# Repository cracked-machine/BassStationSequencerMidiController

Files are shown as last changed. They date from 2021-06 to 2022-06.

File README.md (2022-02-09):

## BassStationMidiController

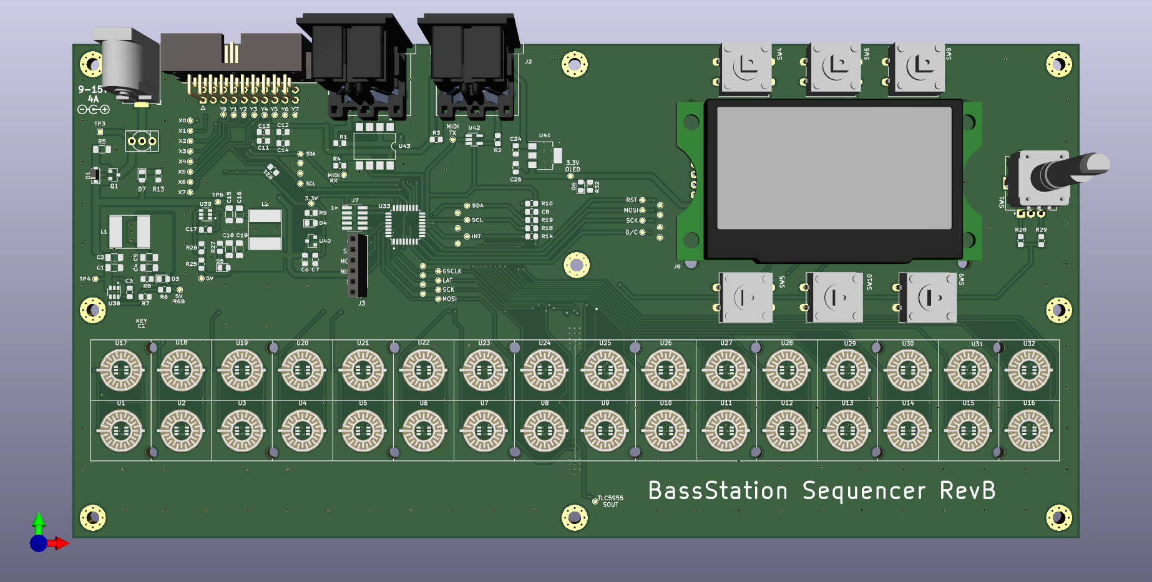
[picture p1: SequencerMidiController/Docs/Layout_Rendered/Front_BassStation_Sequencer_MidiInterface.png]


### Discussion and Design

- [Part1 – The Synth](https://www.bitshiftmyrobot.com/2021/05/26/novation-bass-station-sequencer-part1/)
- [Part2 – Output](https://www.bitshiftmyrobot.com/2021/06/08/novation-bass-station-sequencer-part2/)
- [Part3 - Input](https://www.bitshiftmyrobot.com/2021/06/08/novation-bass-station-sequencer-part3/)
- [Part4 - Power Supply](https://www.bitshiftmyrobot.com/2021/06/10/novation-bass-station-sequencer-part4/)
- [Part5 - User Interface](https://www.bitshiftmyrobot.com/2021/06/11/novation-bass-station-sequencer-part5-user-interface/)
- [Part6 - Final Design](https://www.bitshiftmyrobot.com/2021/06/13/novation-bass-station-sequencer-part6-bringing-it-all-together/)

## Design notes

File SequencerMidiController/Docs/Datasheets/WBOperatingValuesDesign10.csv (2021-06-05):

Name | Value | Category | Description
Vout | 5 V | System Information | Operational Output Voltage
Cin IRMS | 1.49 A | Capacitor | Input capacitor RMS ripple current
Cin Pd | 5.04 mW | Capacitor | Input capacitor power dissipation
Cout IRMS | 243.12 mA | Capacitor | Output capacitor RMS ripple current
Cout Pd | 109.64 µW | Capacitor | Output capacitor power dissipation
Duty Cycle | 57.59% | System Information | Duty cycle
Efficiency | 94.3% | System Information | Steady state efficiency
Frequency | 787.55 kHz | System Information | Switching frequency
IC Tj | 75.41 °C | IC | IC junction temperature
ICThetaJA | 62.9 °C/W | IC | IC junction-to-ambient thermal resistance
L Ipp | 842.18 mA | Inductor | Peak-to-peak inductor ripple current
L Pd | 181.18 mW | Inductor | Inductor power dissipation
IC Pd | 721.86 mW | IC | IC power dissipation
Pout | 15 W | System Information | Total output power
Iin Avg | 1.77 A | IC | Average input current
Mode | CCM | System Information | Conduction Mode
Vout p-p | 14.76 mV | System Information | Peak-to-peak output ripple voltage
IC Iq Pd | 1.51 mW | IC | IC Iq Pd
Total Pd | 908.53 mW | Power | Total Power Dissipation
FootPrint | 164 mm² | System Information | Total Foot Print Area of BOM components
Vin | 9 V | System Information | Vin operating point
Iout | 3 A | System Information | Iout operating point
Cin Pd | 5.04 mW | Power | Input capacitor power dissipation
Cout Pd | 109.64 µW | Power | Output capacitor power dissipation
L Pd | 181.18 mW | Power | Inductor power dissipation
IC Pd | 721.86 mW | Power | IC power dissipation
Vout Actual | 5.03 V | System Information | Vout Actual calculated based on selected voltage divider resistors
Vout Tolerance | 3.05% | System Information | Vout Tolerance based on IC Tolerance (no load) and voltage divider resistors if applicable
Total BOM | $1.00 | System Information | Total BOM Cost
BOM Count | 9 | System Information | Total Design BOM count

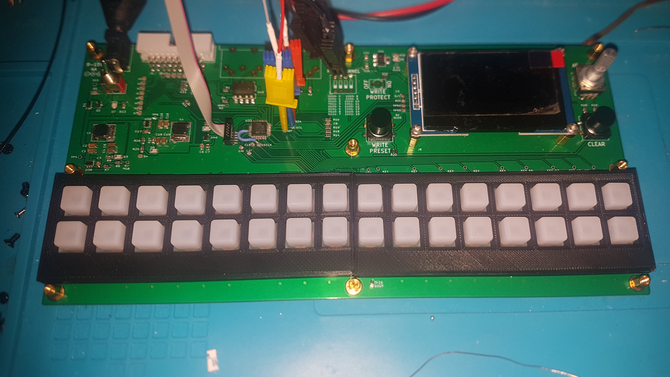
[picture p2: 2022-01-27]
keypad_spacers.jpg

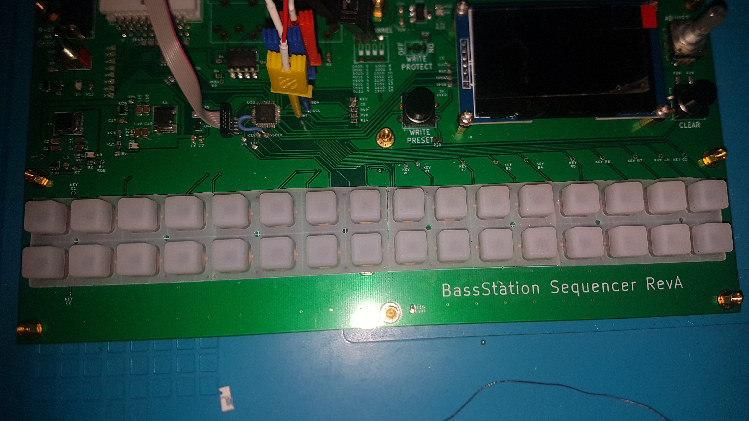
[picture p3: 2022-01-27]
without_keypad_spacer.jpg

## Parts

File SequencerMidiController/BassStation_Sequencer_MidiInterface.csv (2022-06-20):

Comment | Designator | Footprint | LCSC
100nF | C3,C8,C9,C10,C11,C12,C17,C20,C21 | Capacitor_SMD:C_0805_2012Metric_Pad1.18x1.45mm_HandSolder
10uF | C7,C13,C14 | Capacitor_SMD:C_0805_2012Metric_Pad1.18x1.45mm_HandSolder
10uF 20V X5R | C1,C2,C15,C16 | Resistor_SMD:R_1206_3216Metric_Pad1.30x1.75mm_HandSolder
22uF 10V X5R | C4,C5,C18,C19 | Resistor_SMD:R_1206_3216Metric_Pad1.30x1.75mm_HandSolder
4.7uF | C22,C23 | Capacitor_SMD:C_0805_2012Metric_Pad1.18x1.45mm_HandSolder
1uF | C6,C24,C25 | Capacitor_SMD:C_0805_2012Metric_Pad1.18x1.45mm_HandSolder
MMSZ4694T1G | D1 | Diode_SMD:D_SOD-123F
1N4148 | D2 | Diode_SMD:D_SOD-123F
RED | D3,D4,D5,D6,D7 | LED_SMD:LED_0805_2012Metric_Pad1.15x1.40mm_HandSolder
MIDI_IN | J1 | RS_5P180_DIN5_SOCKET_WSHIELD:RS_5P180_DIN5_SOCKET_WSHIELD
MIDI_OUT | J2 | RS_5P180_DIN5_SOCKET_WSHIELD:RS_5P180_DIN5_SOCKET_WSHIELD
Conn_01x06 | J3 | Connector_PinSocket_2.54mm:PinSocket_1x06_P2.54mm_Vertical
Conn_02x10_Odd_Even | J4 | Connector_IDC:IDC-Header_2x10_P2.54mm_Horizontal
Barrel_Jack_Switch | J5 | Connector_BarrelJack:BarrelJack_Horizontal
Conn_02x05_Odd_Even | J7 | Connector_PinHeader_1.27mm:PinHeader_2x05_P1.27mm_Vertical_SMD
Conn_01x07 | J8 | 2.42Inch_OLED_SSD1309:2.42Inch_OLED_SSD1309
Jumper_NC_Small | JP1,JP2,JP3 | Jumper:SolderJumper-2_P1.3mm_Bridged_RoundedPad1.0x1.5mm
4.7uH | L1,L2 | Inductor_SMD:L_Taiyo-Yuden_NR-80xx_HandSoldering
Si2323DS | Q1 | Package_TO_SOT_SMD:SOT-23
220R | R1,R2,R3 | Resistor_SMD:R_0805_2012Metric_Pad1.20x1.40mm_HandSolder
4K7 | R4,R10,R14,R18,R19 | Resistor_SMD:R_0805_2012Metric_Pad1.20x1.40mm_HandSolder
220R | R11,R12 | Capacitor_SMD:C_0805_2012Metric_Pad1.18x1.45mm_HandSolder
10K | R7,R21,R22,R23,R24,R26,R28,R29 | Resistor_SMD:R_0805_2012Metric_Pad1.20x1.40mm_HandSolder
56K | R6,R25 | Resistor_SMD:R_0805_2012Metric_Pad1.20x1.40mm_HandSolder
2K2 | R8,R9,R13,R27,R32 | Resistor_SMD:R_0805_2012Metric_Pad1.20x1.40mm_HandSolder
100R | R5 | Resistor_SMD:R_1206_3216Metric_Pad1.30x1.75mm_HandSolder
RotaryEncoder_Switch | SW1 | Rotary_Encoder:RotaryEncoder_Alps_EC12E-Switch_Vertical_H20mm
SW_SPST | SW3 | DailywellSwitches:Dailywell_SPDT
SW_SPST | SW4,SW5,SW6,SW8,SW9,SW10 | Button_Switch_THT:SW_PUSH-12mm
TestPoint | TP3 | TestPoint:TestPoint_Pad_1.0x1.0mm
TestPoint | TP1,TP2,TP4,TP5,TP6,TP7,TP8,TP9,TP10,TP11,TP12,TP13,TP14,TP15,TP16,TP17,TP18,TP19,TP20,TP21,TP22,TP23,TP32,TP33,TP34,TP35,TP36,TP37,TP38,TP39,TP40,TP41,TP42,TP43,TP44,TP45,TP46,TP47,TP48,TP49,TP50,TP51,TP52,TP53,TP54,TP55,TP56,TP57,TP58,TP59,TP60 | TestPoint:TestPoint_Pad_D1.0mm
PCB-SPST_RGB-LED-Counter-Clockwise | U1,U2,U3,U4,U5,U6,U7,U8,U9,U10,U11,U12,U13,U14,U15,U16,U17,U18,U19,U20,U21,U22,U23,U24,U25,U26,U27,U28,U29,U30,U31,U32 | PCB_SW_LED:Circular_3mm_10mm_Cree_PLLC6_CLY6D-FKC-CK1N1D1BB7D3D3
STM32G0B1_KxTxN_LQFP32 | U33 | Package_QFP:LQFP-32_7x7mm_P0.8mm
ADG2188 | U34 | Package_DFN_QFN:QFN-32-1EP_5x5mm_P0.5mm_EP3.1x3.1mm_ThermalVias
ADP5587-ACPZ_LFCSP24 | U35 | Package_CSP:LFCSP-24-1EP_4x4mm_P0.5mm_EP2.3x2.3mm
TLC5955DCA_HTSSOP56 | U36,U37 | Package_SO:HTSSOP-56-1EP_6.1x14mm_P0.5mm_EP3.61x6.35mm
TPS563200 | U38,U39 | Package_TO_SOT_SMD:SOT-23-6
SE8233X2 | U40 | Package_TO_SOT_SMD:SOT-23
MCP1703A-3302_SOT223 | U41 | Package_TO_SOT_SMD:SOT-223-3_TabPin2
74LVC1G34 | U42 | Package_TO_SOT_SMD:SOT-23-5_HandSoldering
6N135S | U43 | Package_DIP:SMDIP-8_W9.53mm

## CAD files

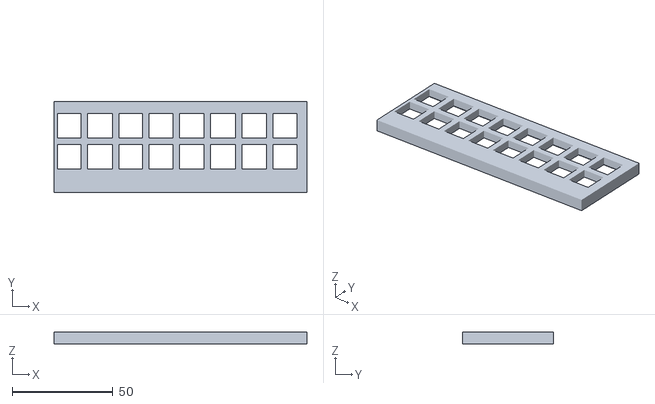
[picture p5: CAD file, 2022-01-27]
KeyPadSpacer_mirroredV0.8 v11.stl
125.4 x 45.0 x 6.00

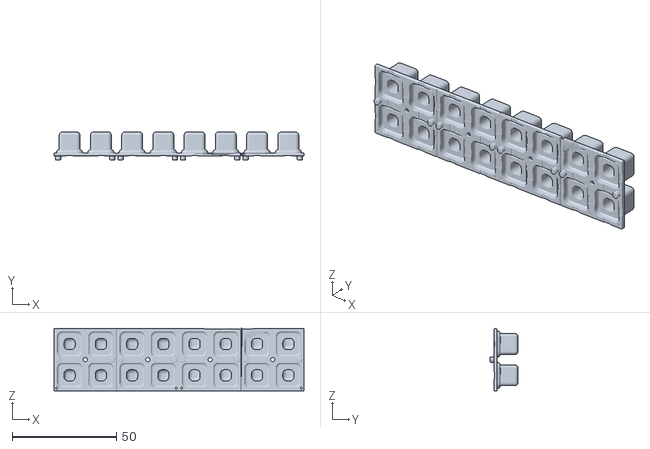
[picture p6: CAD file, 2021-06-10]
SequencerMidiController/Docs/3d/Adafruit1611_2x8_joined-Adafruit_Trellis_3mm_002.stl
120.0 x 13.5 x 30.2

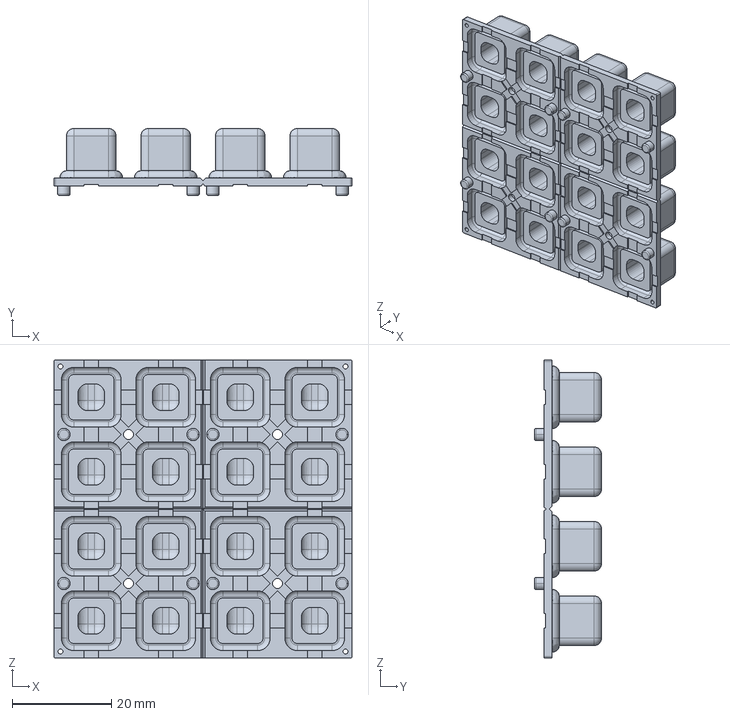
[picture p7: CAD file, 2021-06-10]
SequencerMidiController/Docs/3d/Adafruit Trellis 3mm.stp
60.0 x 13.5 x 60.0 mm

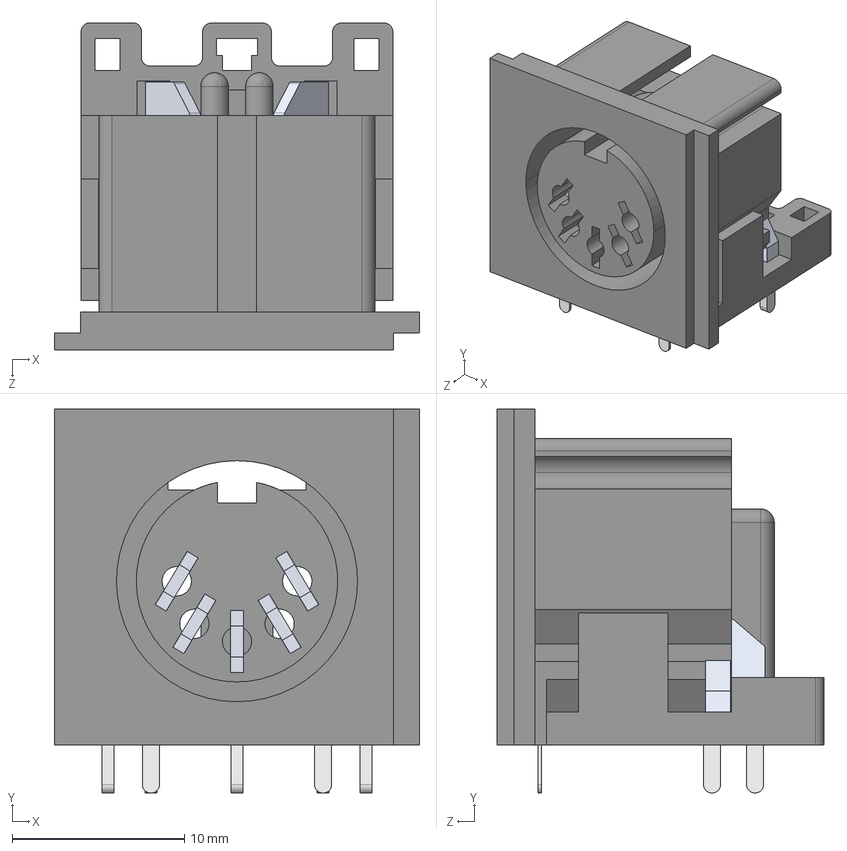
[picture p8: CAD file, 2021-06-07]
SequencerMidiController/Docs/3d/User Library-DIN-5.STEP
21.2 x 22.3 x 19.0 mm
DIN5 A
DIN5 B
DIN5 C
DIN D x 2
DIN E x 2
DIN EE x 2
DIN G
DIN DD x 2

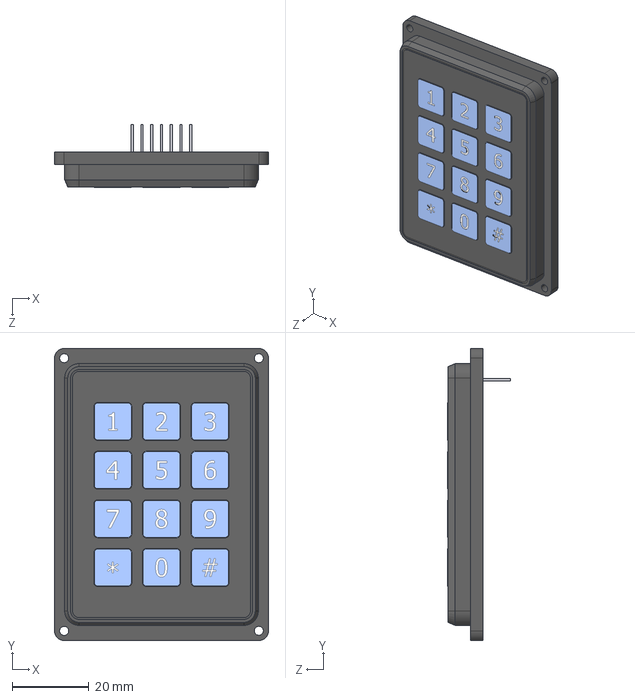
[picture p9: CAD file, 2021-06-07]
SequencerMidiController/Docs/3d/User Library-GrayhillKeypad.STEP
55.9 x 76.2 x 16.4 mm

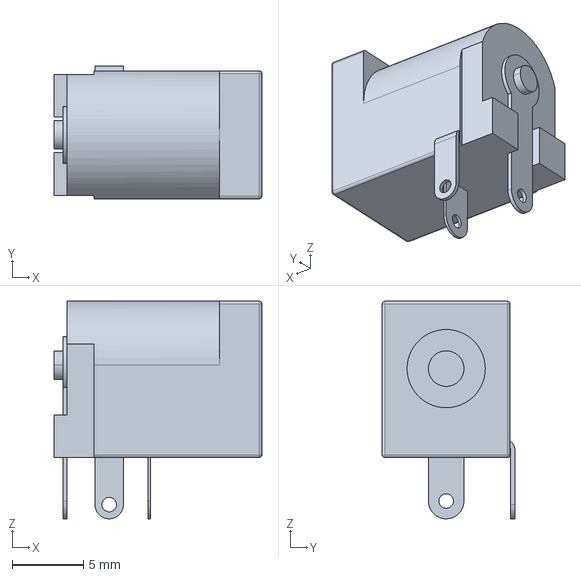
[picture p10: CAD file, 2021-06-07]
SequencerMidiController/Docs/3d/EJ503B-ND.stp
14.6 x 9.32 x 15.3 mm

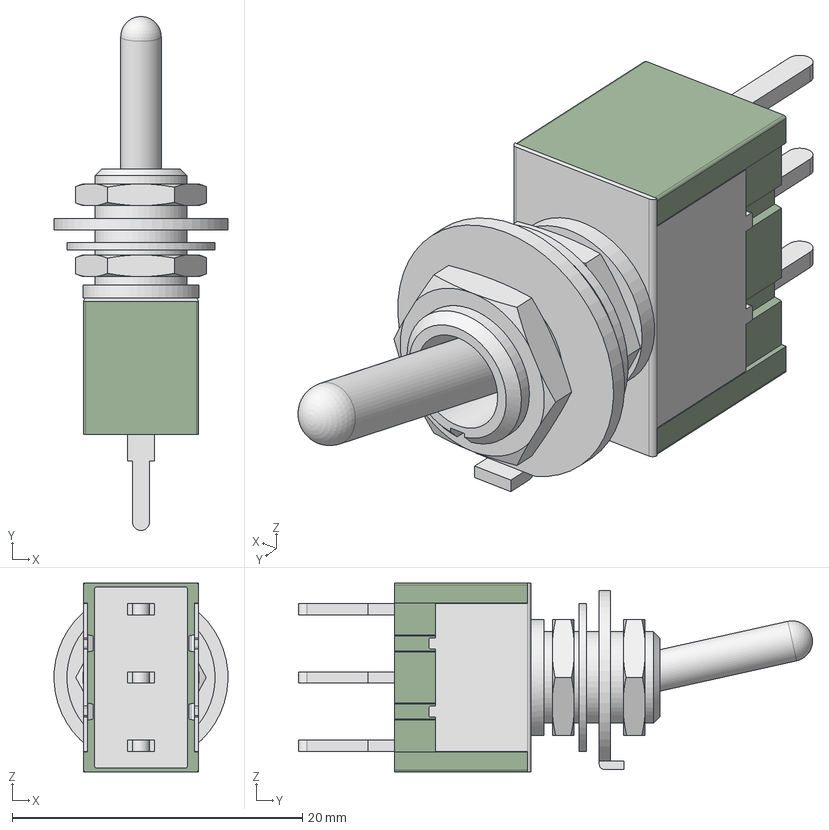
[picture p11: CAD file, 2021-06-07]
SequencerMidiController/Docs/3d/M2012SS1W03.stp
12.0 x 35.4 x 13.0 mm
_M20121SS1W03-switch
_M201S1M201-bushing
_AT513H x 2
_AT507H
_AT509
_M201203-terminals
_M20S-toggles
_M20S-caps

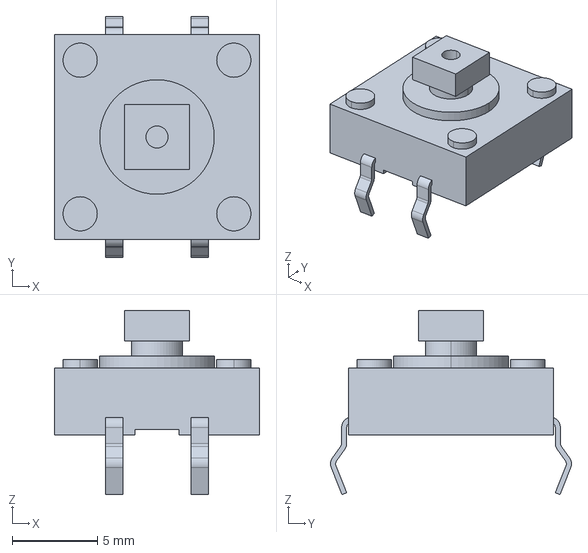
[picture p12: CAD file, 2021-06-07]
SequencerMidiController/Docs/3d/c-1571627-1-e-3d.stp
12.0 x 14.1 x 10.8 mm

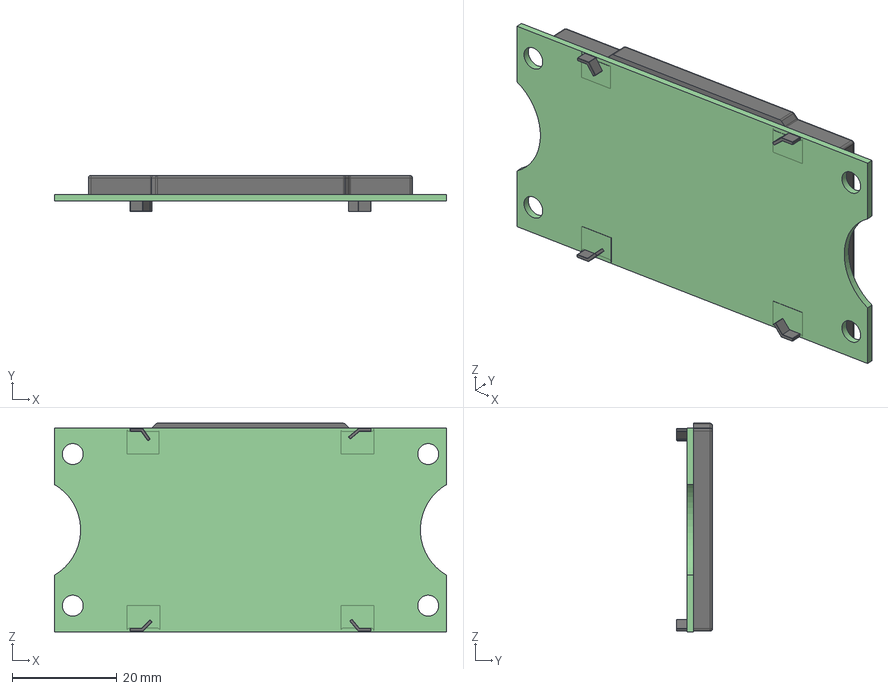
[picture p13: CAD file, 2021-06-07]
SequencerMidiController/Docs/3d/242-oled-v2.step
75.0 x 6.95 x 39.9 mm

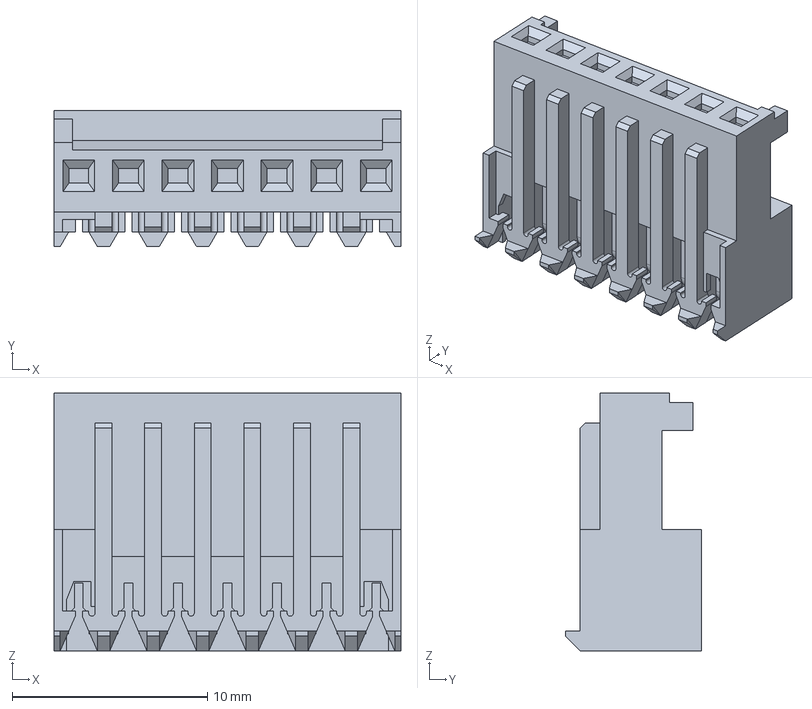
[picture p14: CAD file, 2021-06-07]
SequencerMidiController/Docs/3d/c-3-643813-7-k-3d.stp
17.8 x 6.98 x 13.2 mm

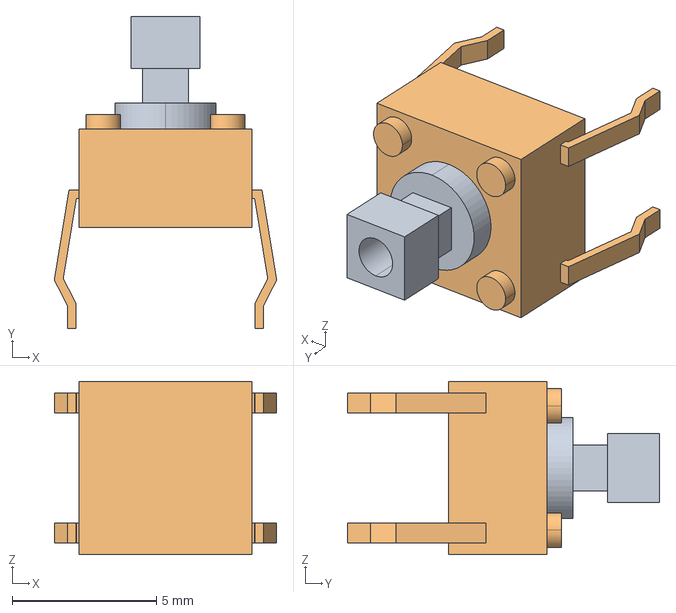
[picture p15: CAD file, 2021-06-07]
SequencerMidiController/Docs/3d/b3f-1056.stp
7.70 x 10.8 x 6.00 mm

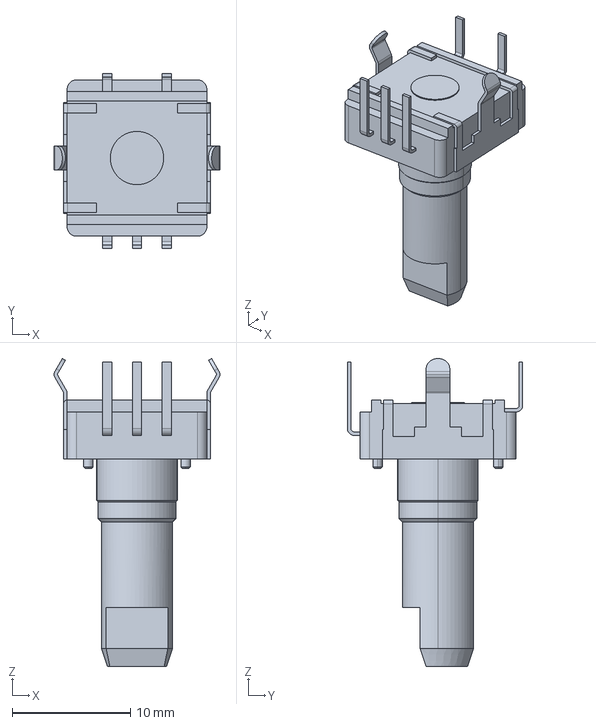
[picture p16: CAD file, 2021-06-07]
SequencerMidiController/Docs/3d/2-1879314-2.stp
14.0 x 14.8 x 26.0 mm

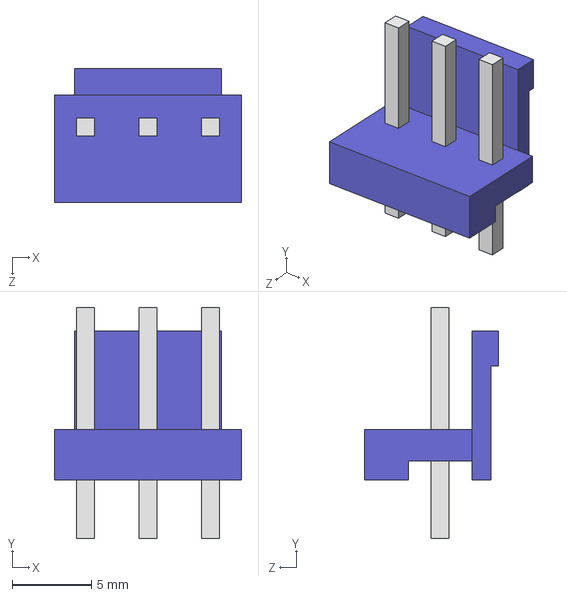
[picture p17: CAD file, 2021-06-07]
SequencerMidiController/Docs/3d/B3P-VH-B.STEP
11.8 x 14.6 x 8.50 mm

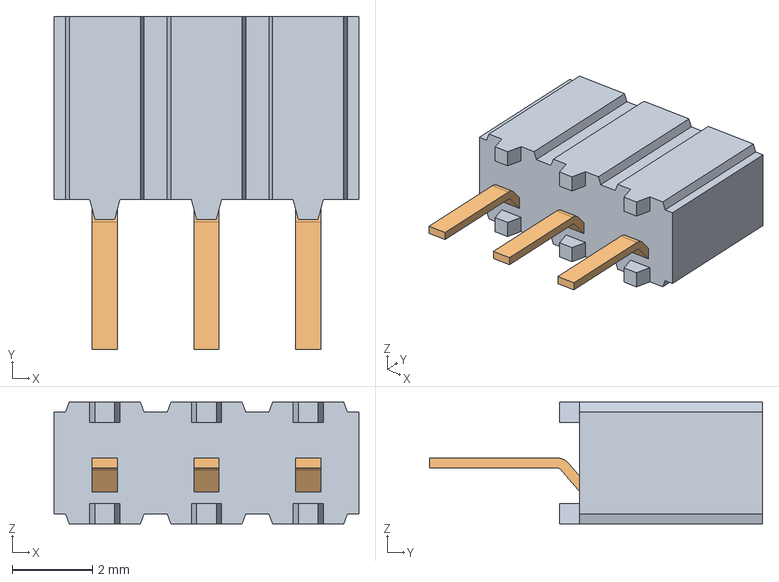
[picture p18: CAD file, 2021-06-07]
SequencerMidiController/Docs/3d/CES-103-01-L-S.stp
7.62 x 8.33 x 3.05 mm
_CES-103-01-S_socket
_C-45-01-03-S

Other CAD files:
KeyPadSpacerV0.8 v11.stl
SequencerMidiController/Docs/3d/89f2962_221790-1.stp
SequencerMidiController/Docs/3d/User Library-Eagle Plastic Devices 45KN018-GRX.STEP
SequencerMidiController/Docs/3d/s2751-46r.stp
SequencerMidiController/Docs/3d/010321021 2.stp
SequencerMidiController/Docs/3d/430450412.stp
SequencerMidiController/Docs/3d/475710001.stp
SequencerMidiController/Docs/3d/559320410.stp
SequencerMidiController/Docs/3d/559320430.stp
SequencerMidiController/Docs/3d/Adafruit Trellis 3mm.stl

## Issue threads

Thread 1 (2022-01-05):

Incorrect silkscreen labelling

cracked-machine, 2022-01-05:
Silk screen: SPI2_CLK and SPI2_LAT labels are incorrectly labelled. They should be switched.

cracked-machine, 2022-02-08:
f82aacb069ef6d8708b5c2ace1307a179e7129ae

Closed 2022-02-08.

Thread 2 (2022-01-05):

STM32G0B1 should use PB6 not PC14 for GSCLK

cracked-machine, 2022-01-05:
PC14 (Pin2) GPIO is too slow (OSC32_IN) for GSCLK.
PB6 (Pin30) GPIO is available and can run much faster.

cracked-machine, 2022-02-08:
f82aacb069ef6d8708b5c2ace1307a179e7129ae

Closed 2022-02-08.

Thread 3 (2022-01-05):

OLED test points are missing their (meaningful) SPI labels

cracked-machine, 2022-01-05:
`TP54` should be `MOSI`
`TP55` should be `SCK`

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

Closed 2022-02-08.

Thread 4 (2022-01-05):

TLC5955 LED driver (U37) should connect SOUT to MCU GPIO for diagnostics

cracked-machine, 2022-01-05:
The datasheet makes this recommendation for `SOUT`

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

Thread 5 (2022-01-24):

"reset" button should be connected to GPIO

cracked-machine, 2022-01-24:
This button would be more useful as a functional button. Maybe replace write protect switch connection to ADP5587, if this switch is no longer needed.

cracked-machine, 2022-02-09:
Reset button removed and more user buttons have been included.

Closed 2022-02-09.

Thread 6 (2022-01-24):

Can SDCard connecter share SPI2 with TLC5955?

cracked-machine, 2022-01-24:
This would allow backup of patterns. Might have issues sharing SPI2 with tlc5955. Obviously sequencer LEDs wwould have to be disabled/frozen while read/write was being done during pattern load/save, but this would be done infrequently upon user request only, so it won't interfere with TLC5955 during normal operation.

cracked-machine, 2022-02-09:
Need to test this with RevA board before committing to a new design.

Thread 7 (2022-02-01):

Add more momentary input buttons below display

cracked-machine, 2022-02-01:

cracked-machine, 2022-02-09:
584c196522adec800601e53ccd521e4a89dbfc55

Closed 2022-02-09.

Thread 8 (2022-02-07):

Add output for volt per division CV

cracked-machine, 2022-02-07:

cracked-machine, 2022-02-09:
Use DAC1_OUT1 on PA4.

cracked-machine, 2022-02-09:
Would need to move 3.3v LDO `MCP1703A-3302_SOT223` (U41)

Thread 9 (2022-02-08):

Add ground test points for every signal test point

cracked-machine, 2022-02-08:

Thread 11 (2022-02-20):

Add ability to detect keypresses from bass station keyboard

cracked-machine, 2022-02-20:
1. User starts the sequencer, the pattern is run
2. User presses a key on the bass station keyboard
3. The sequencer enables the current pattern step and sets it to that note.

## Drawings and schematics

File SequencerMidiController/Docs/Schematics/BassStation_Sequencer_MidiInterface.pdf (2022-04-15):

Input Keyscan and RGB LED Driver

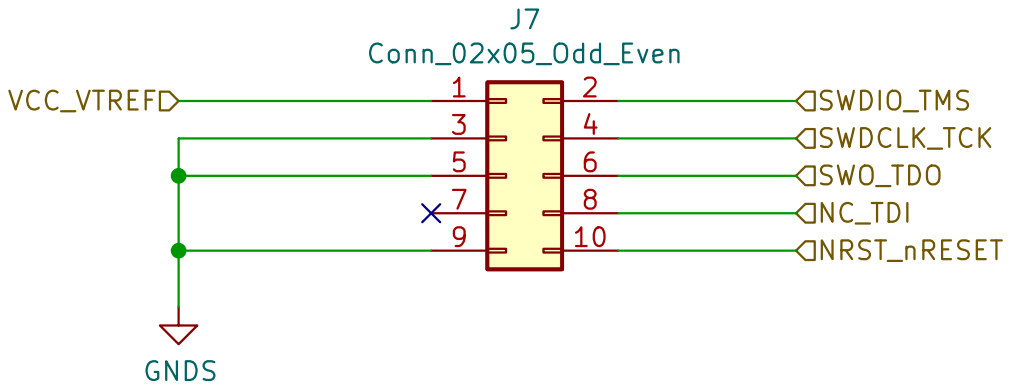
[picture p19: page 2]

File: 10PinARMSWD.kicad_sch Sheet: /MCU/10PinARMSWD/ Created by C Sutton GNDS

Id: 2/47 Title: Debug Connector

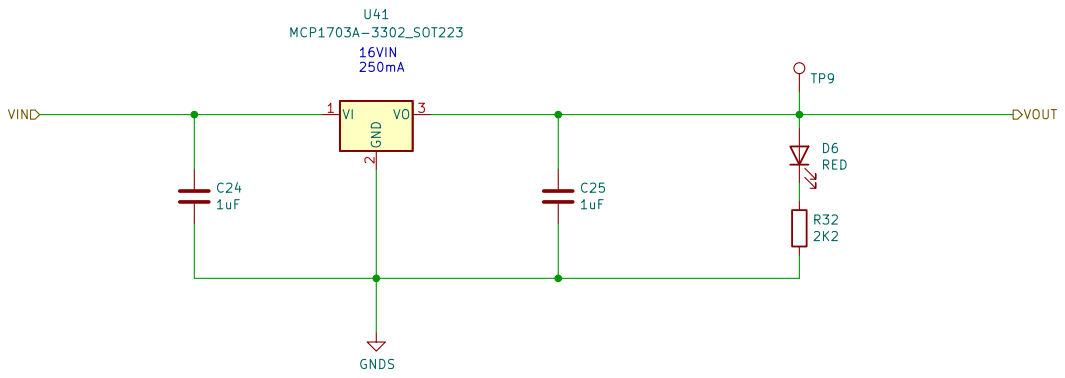
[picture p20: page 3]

Created by C Sutton
Sheet: /PSU/2_42Inch_OLED_LDO/
File: 2_42Inch_OLED_LDO.kicad_sch
Id: 3/47 Title: PSU - LDO 3.3V @ 250mA

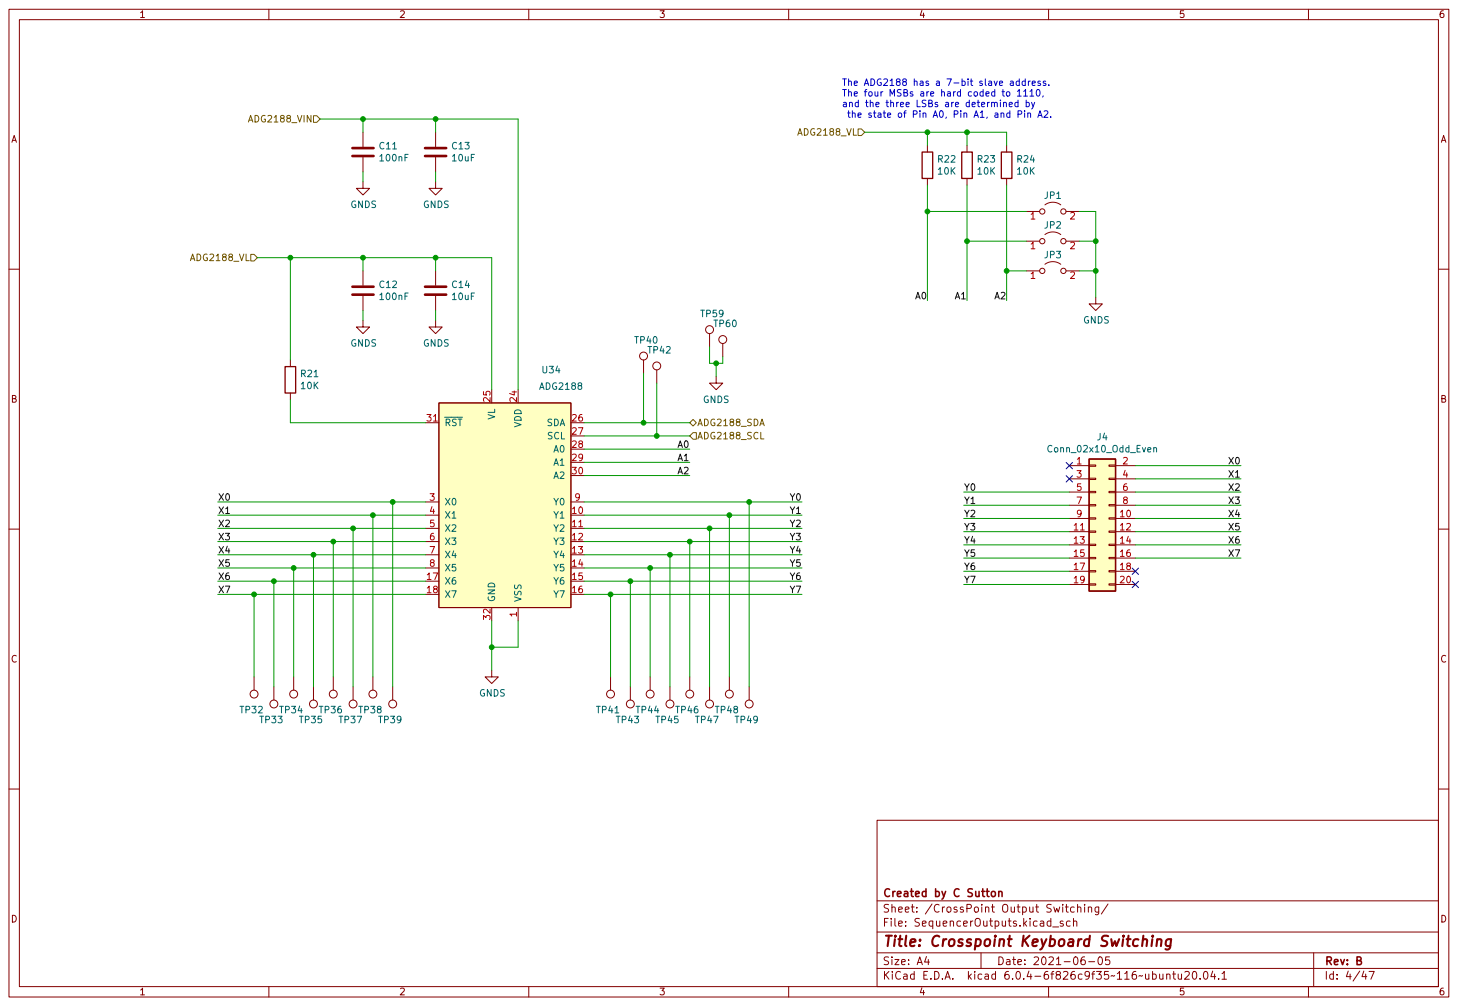
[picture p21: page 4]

The ADG2188 has a 7-bit slave address. The four MSBs are hard coded to 1110, and the three LSBs are determined by

the state of Pin A0, Pin A1, and Pin A2.

1 Y1 10 Y2 11 Y3 12 Y4 13 Y5 14 Y6 15 Y7 16 X6 17 X7 18 VDD 24 VL 25 SDA 26 SCL 27 A0 28 A1 29 X0 3 A2 30 ~{RST} 31 GND 32 X1 4 X2 5 X3 6 X4 7 X5 8 Y0 9 U34 ADG2188 R24

Created by C Sutton
Sheet: /CrossPoint Output Switching/
File: SequencerOutputs.kicad_sch
Id: 4/47 Title: Crosspoint Keyboard Switching

File: Encoder.kicad_sch Sheet: /MCU/Encoder/ Created by C Sutton GNDS

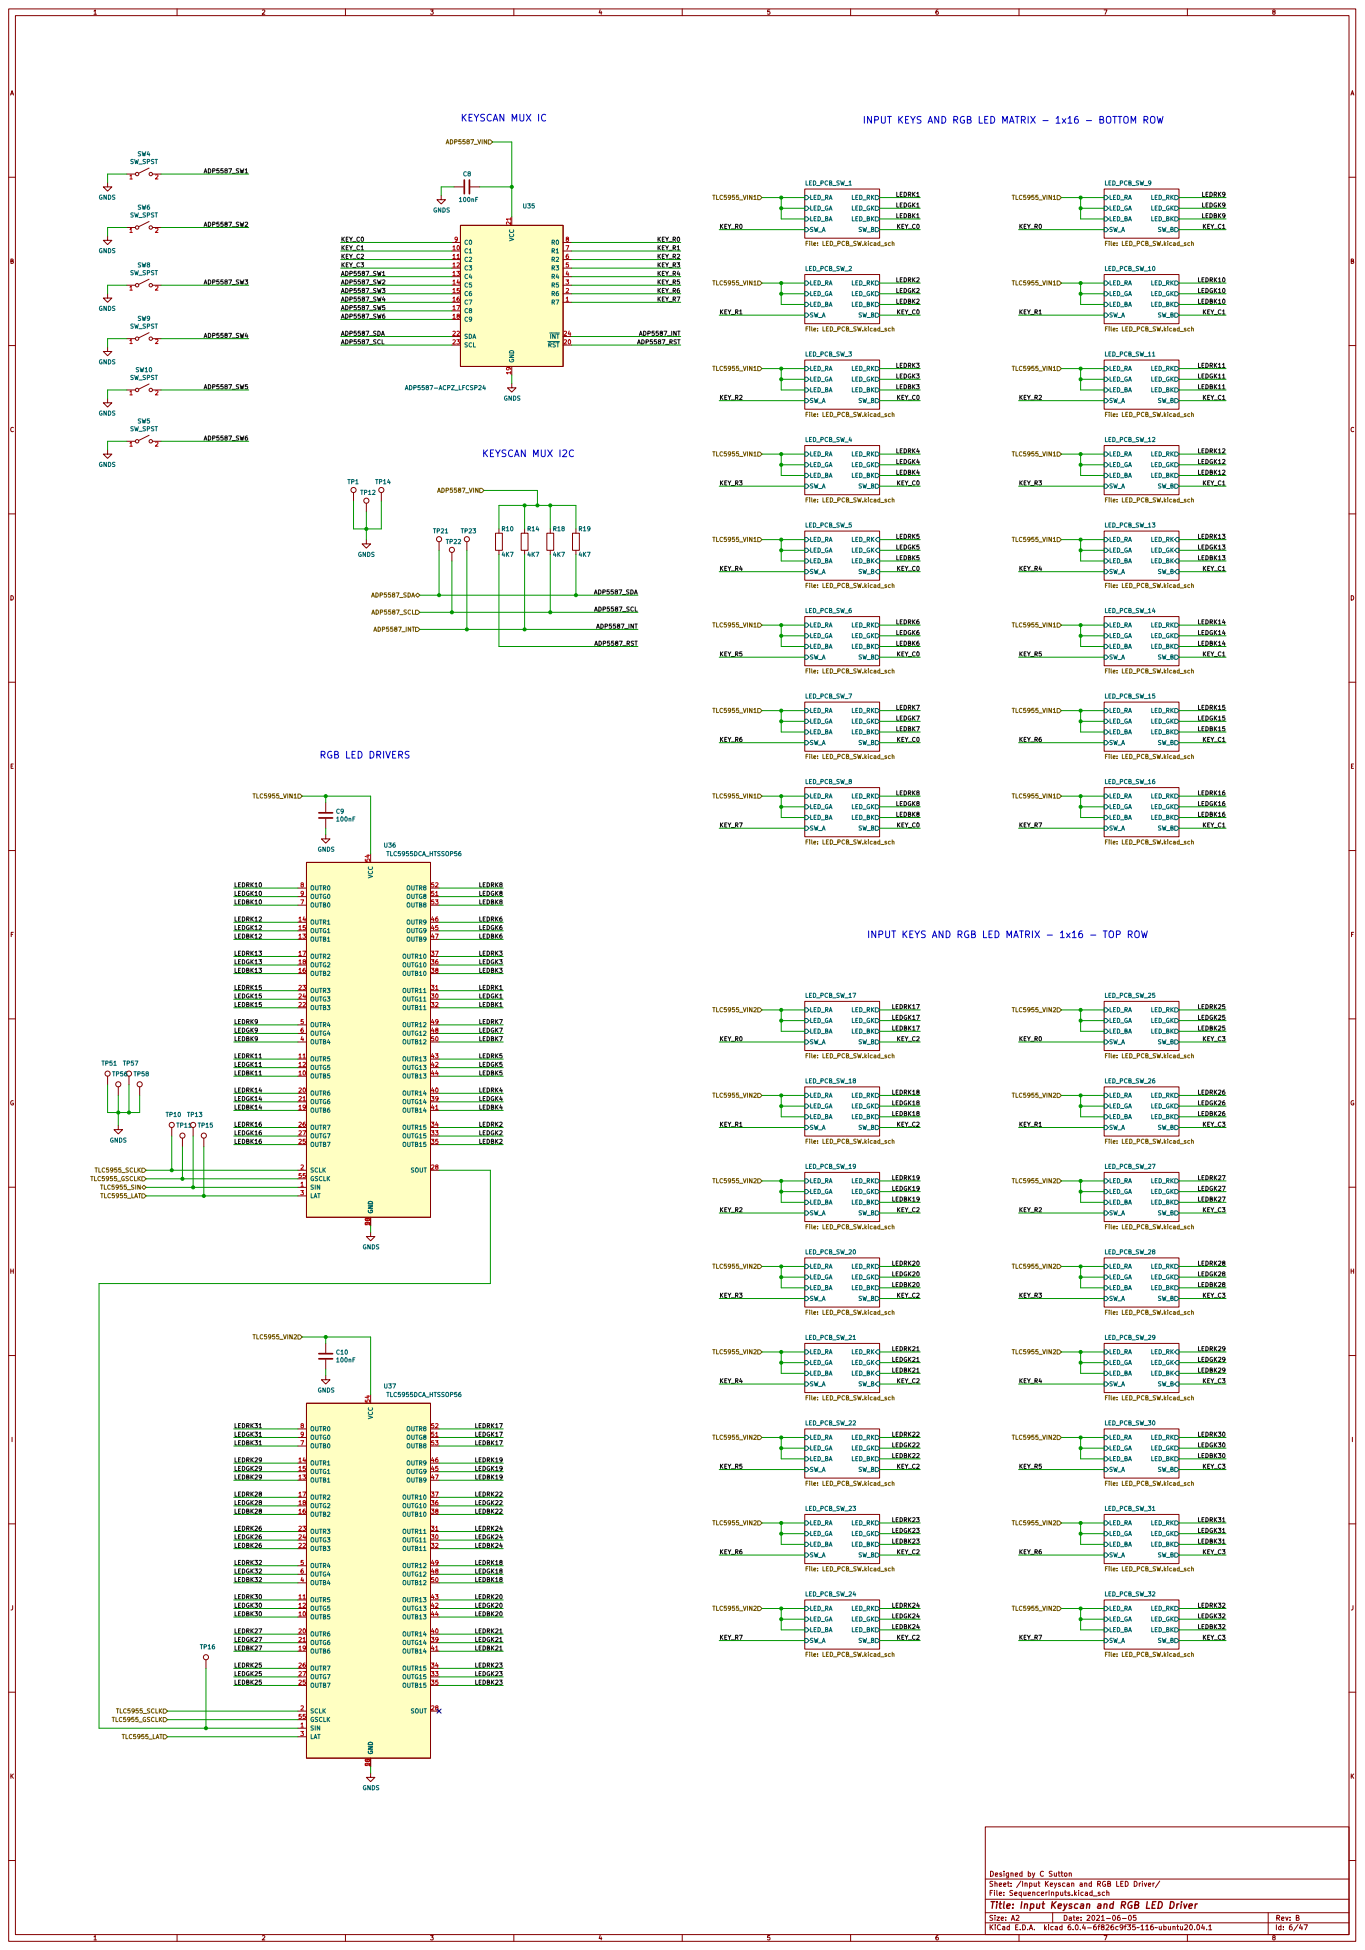
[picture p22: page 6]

INPUT KEYS AND RGB LED MATRIX - 1x16 - BOTTOM ROW
TLC5955_VIN1 TLC5955_VIN1 TLC5955_VIN1

INPUT KEYS AND RGB LED MATRIX - 1x16 - TOP ROW

Designed by C Sutton
Sheet: /Input Keyscan and RGB LED Driver/
File: SequencerInputs.kicad_sch
Id: 6/47 Title: Input Keyscan and RGB LED Driver

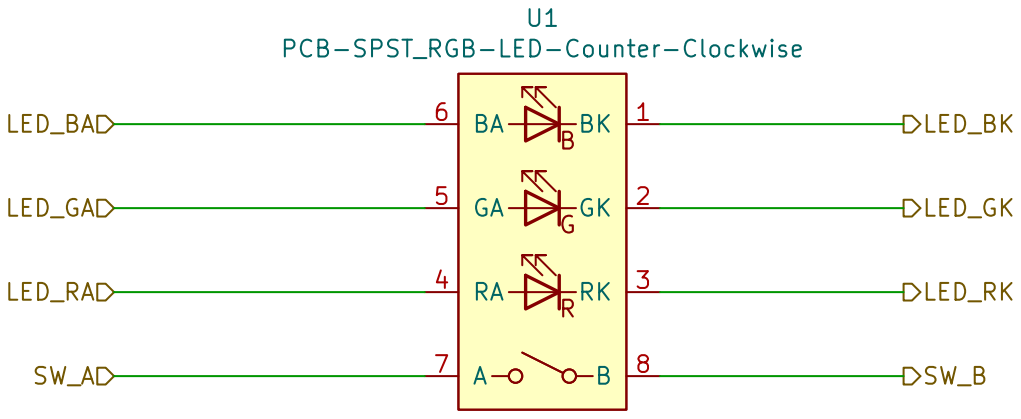
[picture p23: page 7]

8 U1 PCB-SPST_RGB-LED-Counter-Clockwise SW_A

Created by C Sutton
Sheet: /Input Keyscan and RGB LED Driver/LED_PCB_SW_1/
File: LED_PCB_SW.kicad_sch
Id: 7/47 Title: Combined RGB LED and SPST

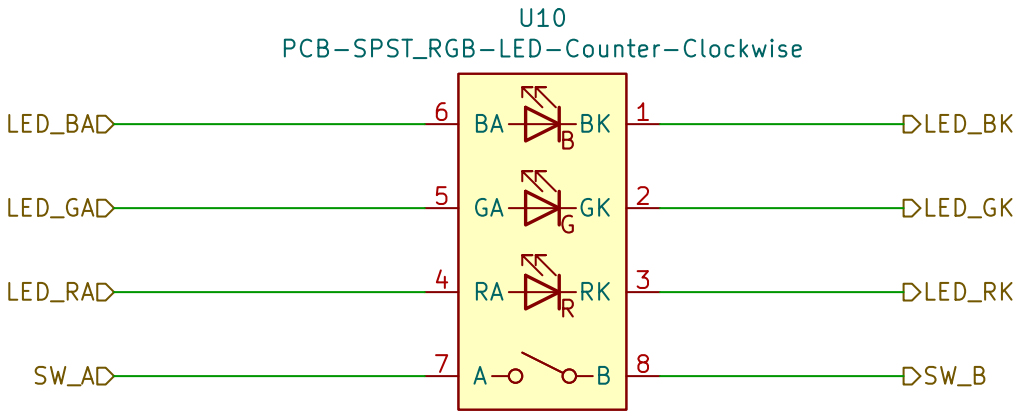
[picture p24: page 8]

8 U10 PCB-SPST_RGB-LED-Counter-Clockwise SW_A

Created by C Sutton
Sheet: /Input Keyscan and RGB LED Driver/LED_PCB_SW_10/
File: LED_PCB_SW.kicad_sch
Id: 8/47 Title: Combined RGB LED and SPST

8 U11 PCB-SPST_RGB-LED-Counter-Clockwise SW_A

Created by C Sutton
Sheet: /Input Keyscan and RGB LED Driver/LED_PCB_SW_11/
File: LED_PCB_SW.kicad_sch
Id: 9/47 Title: Combined RGB LED and SPST

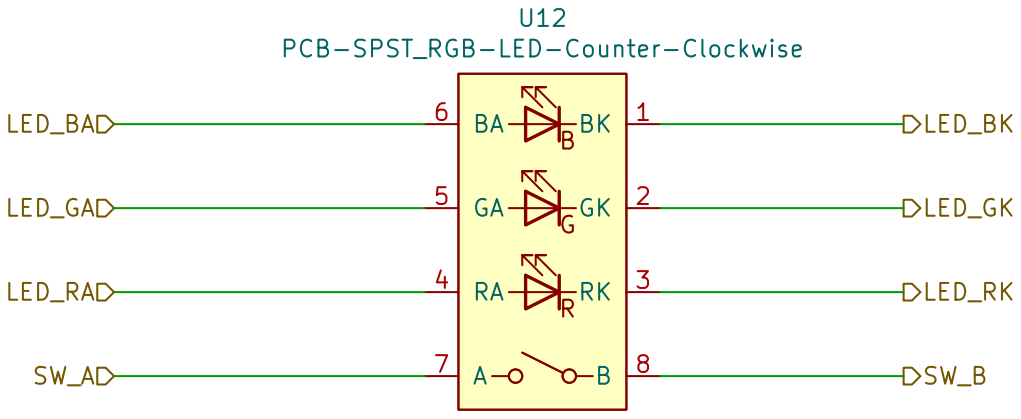
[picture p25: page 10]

8 U12 PCB-SPST_RGB-LED-Counter-Clockwise SW_A

Created by C Sutton
Sheet: /Input Keyscan and RGB LED Driver/LED_PCB_SW_12/
File: LED_PCB_SW.kicad_sch
Id: 10/47 Title: Combined RGB LED and SPST

8 U13 PCB-SPST_RGB-LED-Counter-Clockwise SW_A

Created by C Sutton
Sheet: /Input Keyscan and RGB LED Driver/LED_PCB_SW_13/
File: LED_PCB_SW.kicad_sch
Id: 11/47 Title: Combined RGB LED and SPST

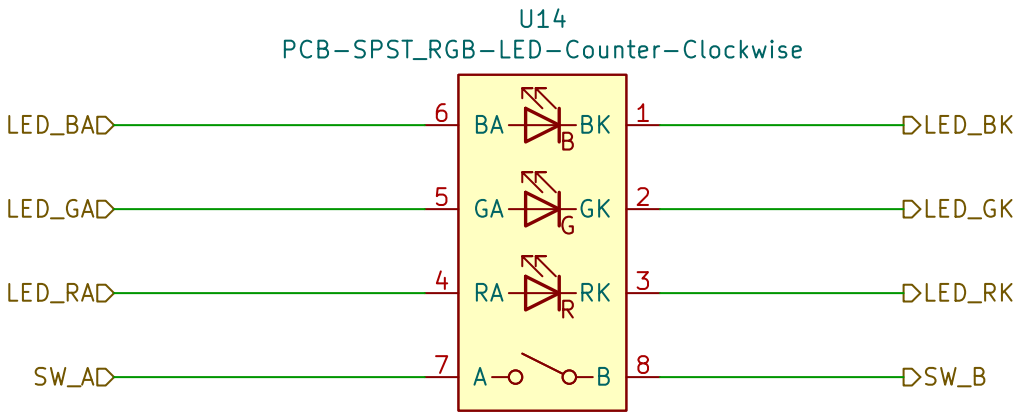
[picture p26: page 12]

8 U14 PCB-SPST_RGB-LED-Counter-Clockwise SW_A

Created by C Sutton
Sheet: /Input Keyscan and RGB LED Driver/LED_PCB_SW_14/
File: LED_PCB_SW.kicad_sch
Id: 12/47 Title: Combined RGB LED and SPST

8 U15 PCB-SPST_RGB-LED-Counter-Clockwise SW_A

Created by C Sutton
Sheet: /Input Keyscan and RGB LED Driver/LED_PCB_SW_15/
File: LED_PCB_SW.kicad_sch
Id: 13/47 Title: Combined RGB LED and SPST

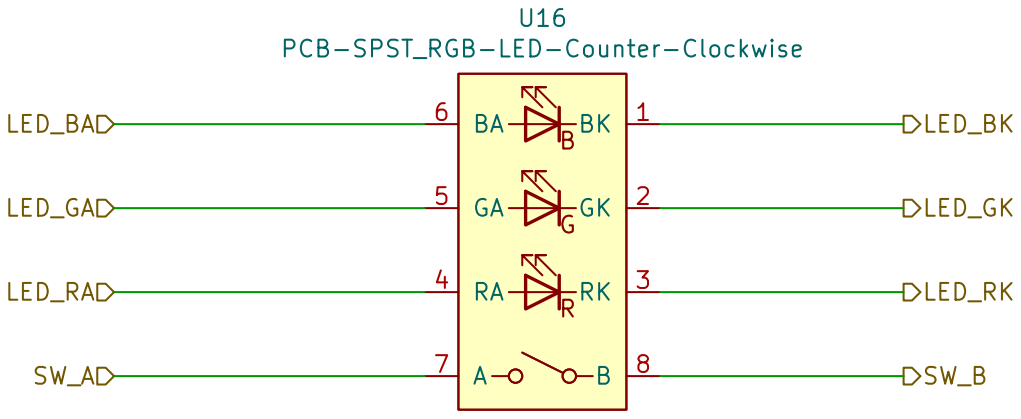
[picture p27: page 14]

8 U16 PCB-SPST_RGB-LED-Counter-Clockwise SW_A

Created by C Sutton
Sheet: /Input Keyscan and RGB LED Driver/LED_PCB_SW_16/
File: LED_PCB_SW.kicad_sch
Id: 14/47 Title: Combined RGB LED and SPST

8 U17 PCB-SPST_RGB-LED-Counter-Clockwise SW_A

Created by C Sutton
Sheet: /Input Keyscan and RGB LED Driver/LED_PCB_SW_17/
File: LED_PCB_SW.kicad_sch
Id: 15/47 Title: Combined RGB LED and SPST

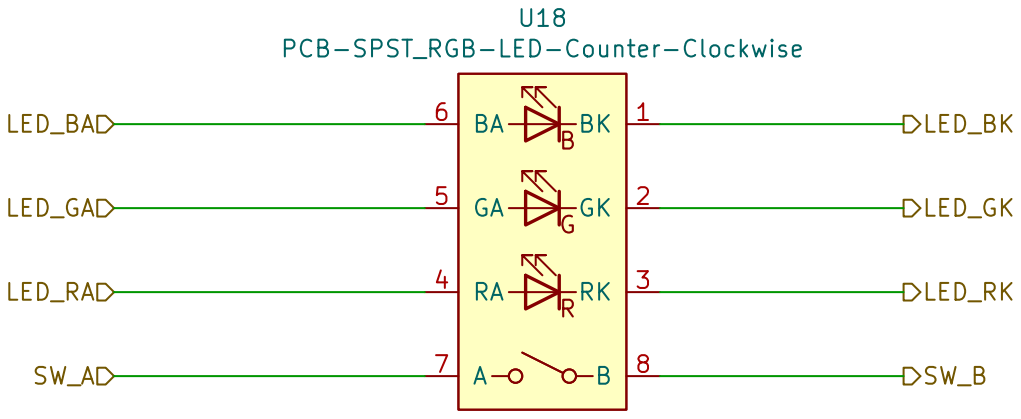
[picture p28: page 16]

8 U18 PCB-SPST_RGB-LED-Counter-Clockwise SW_A

Created by C Sutton
Sheet: /Input Keyscan and RGB LED Driver/LED_PCB_SW_18/
File: LED_PCB_SW.kicad_sch
Id: 16/47 Title: Combined RGB LED and SPST

8 U19 PCB-SPST_RGB-LED-Counter-Clockwise SW_A

Created by C Sutton
Sheet: /Input Keyscan and RGB LED Driver/LED_PCB_SW_19/
File: LED_PCB_SW.kicad_sch
Id: 17/47 Title: Combined RGB LED and SPST

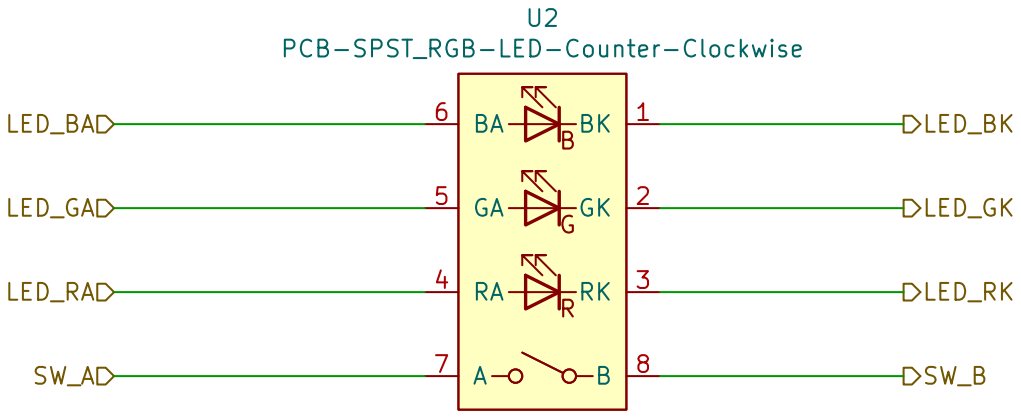
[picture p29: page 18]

8 U2 PCB-SPST_RGB-LED-Counter-Clockwise SW_A

Created by C Sutton
Sheet: /Input Keyscan and RGB LED Driver/LED_PCB_SW_2/
File: LED_PCB_SW.kicad_sch
Id: 18/47 Title: Combined RGB LED and SPST

8 U20 PCB-SPST_RGB-LED-Counter-Clockwise SW_A

Created by C Sutton
Sheet: /Input Keyscan and RGB LED Driver/LED_PCB_SW_20/
File: LED_PCB_SW.kicad_sch
Id: 19/47 Title: Combined RGB LED and SPST

8 U21 PCB-SPST_RGB-LED-Counter-Clockwise SW_A

Created by C Sutton
Sheet: /Input Keyscan and RGB LED Driver/LED_PCB_SW_21/
File: LED_PCB_SW.kicad_sch
Id: 20/47 Title: Combined RGB LED and SPST

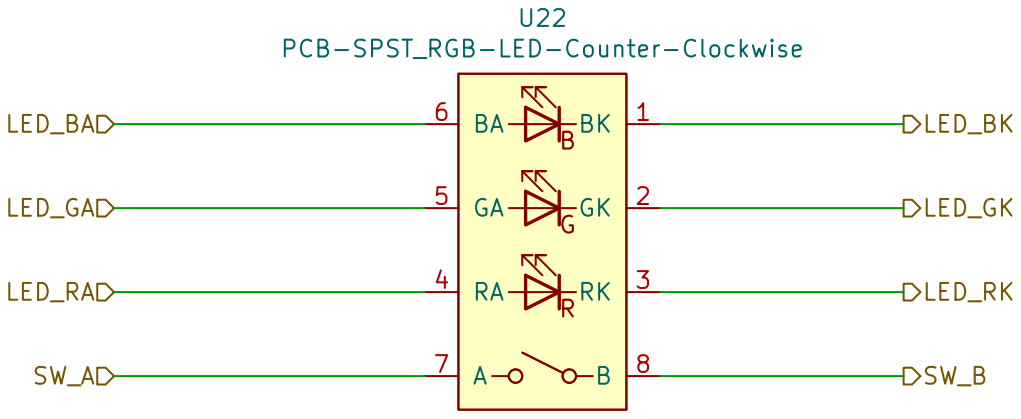
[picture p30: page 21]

8 U22 PCB-SPST_RGB-LED-Counter-Clockwise SW_A

Created by C Sutton
Sheet: /Input Keyscan and RGB LED Driver/LED_PCB_SW_22/
File: LED_PCB_SW.kicad_sch
Id: 21/47 Title: Combined RGB LED and SPST

8 U23 PCB-SPST_RGB-LED-Counter-Clockwise SW_A

Created by C Sutton
Sheet: /Input Keyscan and RGB LED Driver/LED_PCB_SW_23/
File: LED_PCB_SW.kicad_sch
Id: 22/47 Title: Combined RGB LED and SPST

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

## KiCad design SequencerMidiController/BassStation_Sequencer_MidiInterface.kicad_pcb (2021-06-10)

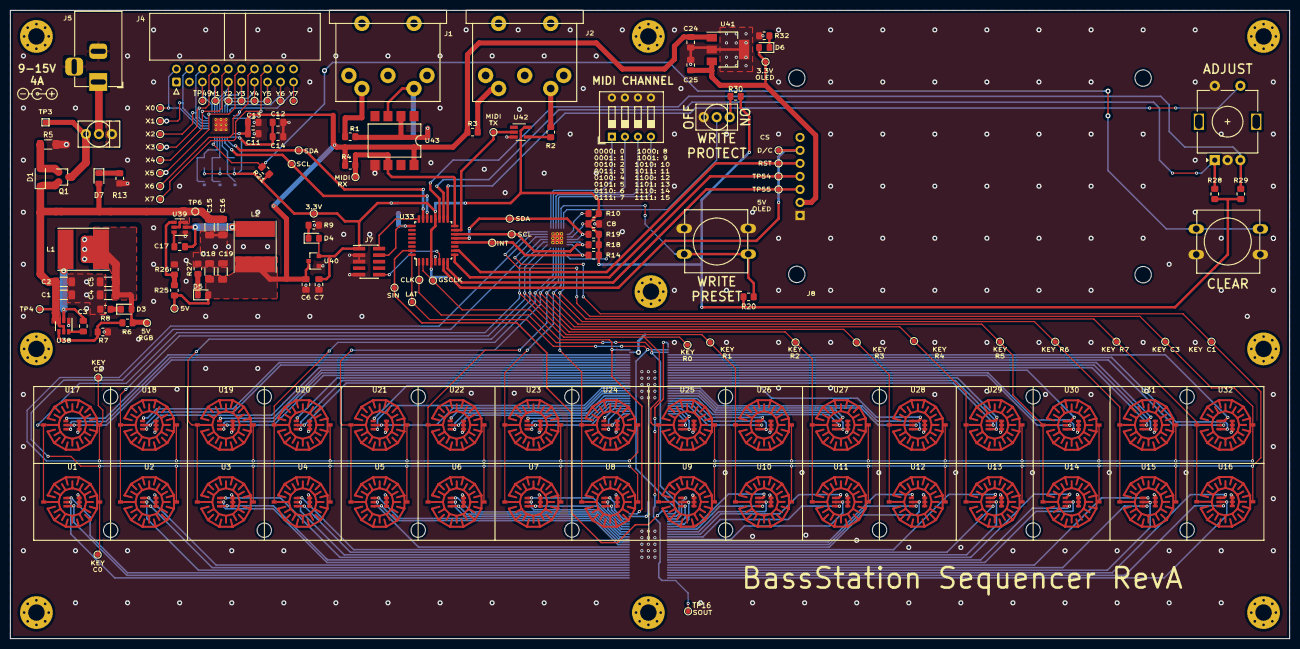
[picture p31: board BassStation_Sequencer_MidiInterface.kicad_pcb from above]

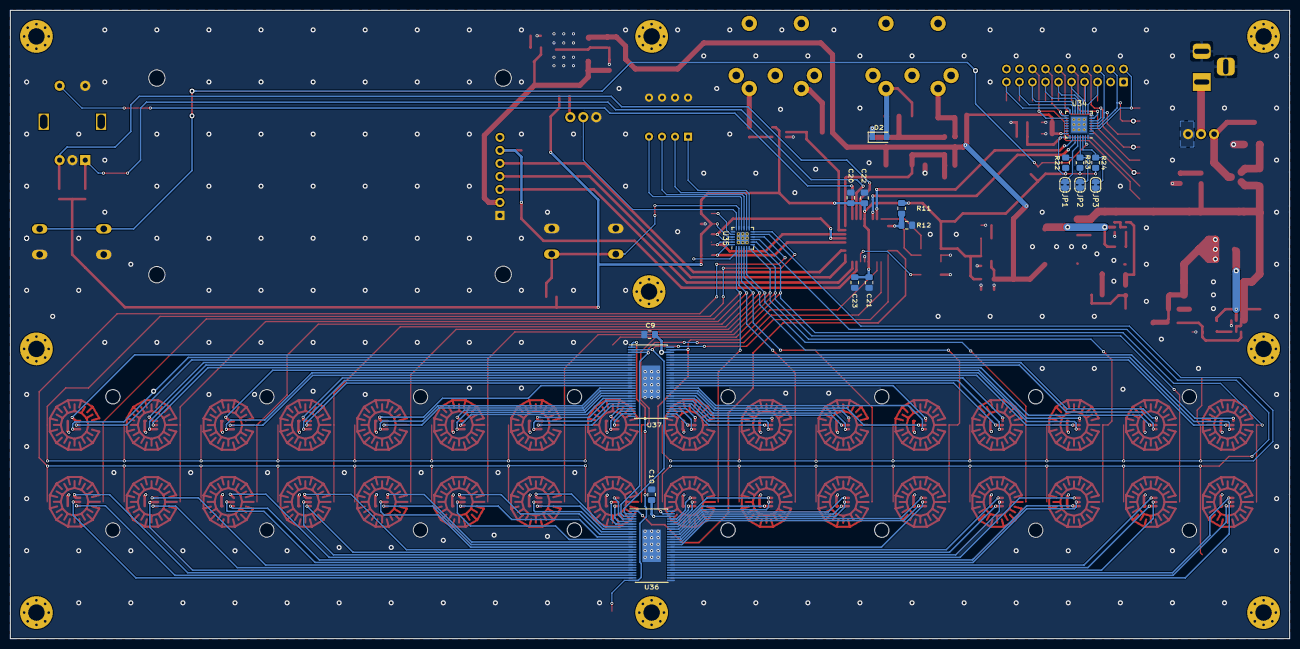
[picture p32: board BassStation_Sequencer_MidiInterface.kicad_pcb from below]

Board: 4 copper layers, 249.6 x 122.6 mm, 172 parts (19 on the bottom side), 184 nets.

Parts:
C1, C2, C15, C16: 10uF 20V X5R; R_1206_3216Metric_Pad1.30x1.75mm_HandSolder
C3, C8, C9, C10, C11, C12, C17, C20, C21: 100nF; C_0805_2012Metric_Pad1.18x1.45mm_HandSolder
C4, C5, C18, C19: 22uF 10V X5R; R_1206_3216Metric_Pad1.30x1.75mm_HandSolder
C6, C24, C25: 1uF; C_0805_2012Metric_Pad1.18x1.45mm_HandSolder
C7, C13, C14: 10uF; C_0805_2012Metric_Pad1.18x1.45mm_HandSolder
C22, C23: 4.7uF; C_0805_2012Metric_Pad1.18x1.45mm_HandSolder
D1: MMSZ4694T1G; D_SOD-123
D2: 1N4148; D_SOD-123F
D3, D4, D5, D6, D7: RED; LED_0805_2012Metric_Pad1.15x1.40mm_HandSolder
J1: MIDI IN; RS_5P180_DIN5_SOCKET_WSHIELD
J2: MIDI OUT; RS_5P180_DIN5_SOCKET_WSHIELD
J4: Conn_02x10_Odd_Even; IDC-Header_2x10_P2.54mm_Horizontal
J5: Barrel_Jack_Switch; BarrelJack_Horizontal
J7: Conn_02x05_Odd_Even; PinHeader_2x05_P1.27mm_Vertical_SMD
J8: Conn_01x07; 2.42Inch_OLED_SSD1309
JP1, JP2, JP3: Jumper_NC_Small; SolderJumper-2_P1.3mm_Bridged_RoundedPad1.0x1.5mm
L1, L2: 4.7uH; L_Taiyo-Yuden_NR-80xx_HandSoldering
Q1: Si2323DS; SOT-23
R1, R2, R3, R20, R30: 220R; R_0805_2012Metric_Pad1.20x1.40mm_HandSolder
R4, R10, R14, R18, R19: 4K7; R_0805_2012Metric_Pad1.20x1.40mm_HandSolder
R5: 100R; R_1206_3216Metric_Pad1.30x1.75mm_HandSolder
R6, R25: 56K; R_0805_2012Metric_Pad1.20x1.40mm_HandSolder
R7, R21, R22, R23, R24, R26, R28, R29: 10K; R_0805_2012Metric_Pad1.20x1.40mm_HandSolder
R8, R9, R13, R27, R32: 2K2; R_0805_2012Metric_Pad1.20x1.40mm_HandSolder
R11, R12: 220R; C_0805_2012Metric_Pad1.18x1.45mm_HandSolder
SW1: Rotary_Encoder_Switch; RotaryEncoder_Alps_EC11E-Switch_Vertical_H20mm
SW2: SW_SPDT-2MS1T1B1M2QES; Dailywell_SPDT
SW3: SW_SPST; Dailywell_SPDT
SW4: SW_DIP_x04; SW_DIP_SPSTx04_Slide_9.78x12.34mm_W7.62mm_P2.54mm
SW5, SW7: SW_SPST; SW_PUSH-12mm
TP2, TP4, TP5, TP6, TP7, TP8, TP9, TP10, TP11, TP13, TP15, TP16, TP17, TP18, TP19, TP20, TP21, TP22, TP23, TP24, TP25, TP26, TP27, TP28, TP29, TP30, TP31, TP32, TP33, TP34, TP35, TP36, TP37, TP38, TP39, TP40, TP41, TP42, TP43, TP44, TP45, TP46, TP47, TP48, TP49, TP50, TP52, TP53, TP54, TP55: TestPoint; TestPoint_Pad_D1.0mm
TP3: TestPoint; TestPoint_Pad_1.0x1.0mm
U1, U2, U3, U4, U5, U6, U7, U8, U9, U10, U11, U12, U13, U14, U15, U16, U17, U18, U19, U20, U21, U22, U23, U24, U25, U26, U27, U28, U29, U30, U31, U32: PCB-SPST_RGB-LED-Counter-Clockwise; Circular_3mm_10mm_Cree_PLLC6_CLY6D-FKC-CK1N1D1BB7D3D3
U33: STM32G0B1_KxTxN_LQFP32; LQFP-32_7x7mm_P0.8mm
U34: ADG2188; QFN-32-1EP_5x5mm_P0.5mm_EP3.1x3.1mm_ThermalVias
U35: ADP5587-ACPZ_LFCSP24; LFCSP-24-1EP_4x4mm_P0.5mm_EP2.3x2.3mm_ThermalVias
U36, U37: TLC5955DCA_HTSSOP56; HTSSOP-56-1EP_6.1x14mm_P0.5mm_EP3.61x6.35mm
U38, U39: TPS563200; SOT-23-6
U40: SE8233X2; SOT-23
U41: MCP1703A-3302_SOT223; SOT-223-3_TabPin2
U42: 74LVC1G34; SOT-23-5_HandSoldering
U43: 6N135S; SMDIP-8_W9.53mm

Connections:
+3V3: C7.1, C8.1, C12.1, C14.1, C20.1, C21.1, C22.1, C23.1, D4.2, J7.1, R10.2, R11.1, R14.1, R18.2, R19.1, R20.2, R21.1, R22.1, R23.1, R24.1, R28.1, R29.1, R30.2, TP8.1, U33.4, U33.20, U34.25, U35.21, U40.2, U42.5
+5V: C6.1, C11.1, C13.1, C18.1, C19.1, C24.1, D5.2, L2.2, R3.2, R4.2, R25.1, TP7.1, U34.24, U40.3, U41.1, U43.8
/CrossPoint Output Switching/A0: JP1.1, R22.2, U34.28
/CrossPoint Output Switching/A1: JP2.1, R23.2, U34.29
/CrossPoint Output Switching/A2: JP3.1, R24.2, U34.30
/CrossPoint Output Switching/ADG2188_SCL: TP42.1, U33.22, U34.27
/CrossPoint Output Switching/ADG2188_SDA: TP40.1, U33.23, U34.26
/CrossPoint Output Switching/X0: J4.2, TP39.1, U34.3
/CrossPoint Output Switching/X1: J4.4, TP38.1, U34.4
/CrossPoint Output Switching/X2: J4.6, TP37.1, U34.5
/CrossPoint Output Switching/X3: J4.8, TP36.1, U34.6
/CrossPoint Output Switching/X4: J4.10, TP35.1, U34.7
/CrossPoint Output Switching/X5: J4.12, TP34.1, U34.8
/CrossPoint Output Switching/X6: J4.14, TP33.1, U34.17
/CrossPoint Output Switching/X7: J4.16, TP32.1, U34.18
/CrossPoint Output Switching/Y0: J4.5, TP49.1, U34.9
/CrossPoint Output Switching/Y1: J4.7, TP48.1, U34.10
/CrossPoint Output Switching/Y2: J4.9, TP47.1, U34.11
/CrossPoint Output Switching/Y3: J4.11, TP46.1, U34.12
/CrossPoint Output Switching/Y4: J4.13, TP45.1, U34.13
/CrossPoint Output Switching/Y5: J4.15, TP44.1, U34.14
/CrossPoint Output Switching/Y6: J4.17, TP43.1, U34.15
/CrossPoint Output Switching/Y7: J4.19, TP41.1, U34.16
/Input Keyscan and RGB LED Driver/ADP5587_INT: R14.2, TP23.1, U33.12, U35.24
/Input Keyscan and RGB LED Driver/ADP5587_RST: R10.1, U35.20
/Input Keyscan and RGB LED Driver/ADP5587_SCL: R18.1, TP22.1, U33.14, U35.23
/Input Keyscan and RGB LED Driver/ADP5587_SDA: R19.2, TP21.1, U33.13, U35.22
/Input Keyscan and RGB LED Driver/ADP5587_WRITE: R20.1, SW5.2, U35.17
/Input Keyscan and RGB LED Driver/ADP5587_WRITEPROTECT: SW2.2, U35.18
/Input Keyscan and RGB LED Driver/DIPSW1: SW4.1, U35.13
/Input Keyscan and RGB LED Driver/DIPSW2: SW4.2, U35.14
/Input Keyscan and RGB LED Driver/DIPSW3: SW4.3, U35.15
/Input Keyscan and RGB LED Driver/DIPSW4: SW4.4, U35.16
/Input Keyscan and RGB LED Driver/KEY_C0: TP17.1, U1.8, U2.8, U3.8, U4.8, U5.8, U6.8, U7.8, U8.8, U35.9
/Input Keyscan and RGB LED Driver/KEY_C1: TP18.1, U9.8, U10.8, U11.8, U12.8, U13.8, U14.8, U15.8, U16.8, U35.10
/Input Keyscan and RGB LED Driver/KEY_C2: TP19.1, U17.8, U18.8, U19.8, U20.8, U21.8, U22.8, U23.8, U24.8, U35.11
/Input Keyscan and RGB LED Driver/KEY_C3: TP20.1, U25.8, U26.8, U27.8, U28.8, U29.8, U30.8, U31.8, U32.8, U35.12
/Input Keyscan and RGB LED Driver/KEY_R0: TP24.1, U1.7, U9.7, U17.7, U25.7, U35.8
/Input Keyscan and RGB LED Driver/KEY_R1: TP25.1, U2.7, U10.7, U18.7, U26.7, U35.7
/Input Keyscan and RGB LED Driver/KEY_R2: TP26.1, U3.7, U11.7, U19.7, U27.7, U35.6
/Input Keyscan and RGB LED Driver/KEY_R3: TP27.1, U4.7, U12.7, U20.7, U28.7, U35.5
/Input Keyscan and RGB LED Driver/KEY_R4: TP28.1, U5.7, U13.7, U21.7, U29.7, U35.4
/Input Keyscan and RGB LED Driver/KEY_R5: TP29.1, U6.7, U14.7, U22.7, U30.7, U35.3
/Input Keyscan and RGB LED Driver/KEY_R6: TP30.1, U7.7, U15.7, U23.7, U31.7, U35.2
/Input Keyscan and RGB LED Driver/KEY_R7: TP31.1, U8.7, U16.7, U24.7, U32.7, U35.1
/Input Keyscan and RGB LED Driver/LEDBK1: U1.1, U36.32
/Input Keyscan and RGB LED Driver/LEDBK2: U2.1, U36.35
/Input Keyscan and RGB LED Driver/LEDBK3: U3.1, U36.38
/Input Keyscan and RGB LED Driver/LEDBK4: U4.1, U36.41
/Input Keyscan and RGB LED Driver/LEDBK5: U5.1, U36.44
/Input Keyscan and RGB LED Driver/LEDBK6: U6.1, U36.47
/Input Keyscan and RGB LED Driver/LEDBK7: U7.1, U36.50
/Input Keyscan and RGB LED Driver/LEDBK8: U8.1, U36.53
/Input Keyscan and RGB LED Driver/LEDBK9: U9.1, U36.4
/Input Keyscan and RGB LED Driver/LEDBK10: U10.1, U36.7
/Input Keyscan and RGB LED Driver/LEDBK11: U11.1, U36.10
/Input Keyscan and RGB LED Driver/LEDBK12: U12.1, U36.13
/Input Keyscan and RGB LED Driver/LEDBK13: U13.1, U36.16
/Input Keyscan and RGB LED Driver/LEDBK14: U14.1, U36.19
/Input Keyscan and RGB LED Driver/LEDBK15: U15.1, U36.22
/Input Keyscan and RGB LED Driver/LEDBK16: U16.1, U36.25
/Input Keyscan and RGB LED Driver/LEDBK17: U17.1, U37.53
/Input Keyscan and RGB LED Driver/LEDBK18: U18.1, U37.50
/Input Keyscan and RGB LED Driver/LEDBK19: U19.1, U37.47
/Input Keyscan and RGB LED Driver/LEDBK20: U20.1, U37.44
/Input Keyscan and RGB LED Driver/LEDBK21: U21.1, U37.41
/Input Keyscan and RGB LED Driver/LEDBK22: U22.1, U37.38
/Input Keyscan and RGB LED Driver/LEDBK23: U23.1, U37.35
/Input Keyscan and RGB LED Driver/LEDBK24: U24.1, U37.32
/Input Keyscan and RGB LED Driver/LEDBK25: U25.1, U37.25
/Input Keyscan and RGB LED Driver/LEDBK26: U26.1, U37.22
/Input Keyscan and RGB LED Driver/LEDBK27: U27.1, U37.19
/Input Keyscan and RGB LED Driver/LEDBK28: U28.1, U37.16
/Input Keyscan and RGB LED Driver/LEDBK29: U29.1, U37.13
/Input Keyscan and RGB LED Driver/LEDBK30: U30.1, U37.10
/Input Keyscan and RGB LED Driver/LEDBK31: U31.1, U37.7
/Input Keyscan and RGB LED Driver/LEDBK32: U32.1, U37.4
/Input Keyscan and RGB LED Driver/LEDGK1: U1.2, U36.30
/Input Keyscan and RGB LED Driver/LEDGK2: U2.2, U36.33
/Input Keyscan and RGB LED Driver/LEDGK3: U3.2, U36.36
/Input Keyscan and RGB LED Driver/LEDGK4: U4.2, U36.39
/Input Keyscan and RGB LED Driver/LEDGK5: U5.2, U36.42
/Input Keyscan and RGB LED Driver/LEDGK6: U6.2, U36.45
/Input Keyscan and RGB LED Driver/LEDGK7: U7.2, U36.48
/Input Keyscan and RGB LED Driver/LEDGK8: U8.2, U36.51
/Input Keyscan and RGB LED Driver/LEDGK9: U9.2, U36.6
/Input Keyscan and RGB LED Driver/LEDGK10: U10.2, U36.9
/Input Keyscan and RGB LED Driver/LEDGK11: U11.2, U36.12
/Input Keyscan and RGB LED Driver/LEDGK12: U12.2, U36.15
/Input Keyscan and RGB LED Driver/LEDGK13: U13.2, U36.18
/Input Keyscan and RGB LED Driver/LEDGK14: U14.2, U36.21
/Input Keyscan and RGB LED Driver/LEDGK15: U15.2, U36.24
/Input Keyscan and RGB LED Driver/LEDGK16: U16.2, U36.27
/Input Keyscan and RGB LED Driver/LEDGK17: U17.2, U37.51
/Input Keyscan and RGB LED Driver/LEDGK18: U18.2, U37.48
/Input Keyscan and RGB LED Driver/LEDGK19: U19.2, U37.45
/Input Keyscan and RGB LED Driver/LEDGK20: U20.2, U37.42
/Input Keyscan and RGB LED Driver/LEDGK21: U21.2, U37.39
/Input Keyscan and RGB LED Driver/LEDGK22: U22.2, U37.36
/Input Keyscan and RGB LED Driver/LEDGK23: U23.2, U37.33
/Input Keyscan and RGB LED Driver/LEDGK24: U24.2, U37.30
/Input Keyscan and RGB LED Driver/LEDGK25: U25.2, U37.27
/Input Keyscan and RGB LED Driver/LEDGK26: U26.2, U37.24
/Input Keyscan and RGB LED Driver/LEDGK27: U27.2, U37.21
/Input Keyscan and RGB LED Driver/LEDGK28: U28.2, U37.18
/Input Keyscan and RGB LED Driver/LEDGK29: U29.2, U37.15
/Input Keyscan and RGB LED Driver/LEDGK30: U30.2, U37.12
/Input Keyscan and RGB LED Driver/LEDGK31: U31.2, U37.9
/Input Keyscan and RGB LED Driver/LEDGK32: U32.2, U37.6
/Input Keyscan and RGB LED Driver/LEDRK1: U1.3, U36.31
/Input Keyscan and RGB LED Driver/LEDRK2: U2.3, U36.34
/Input Keyscan and RGB LED Driver/LEDRK3: U3.3, U36.37
/Input Keyscan and RGB LED Driver/LEDRK4: U4.3, U36.40
/Input Keyscan and RGB LED Driver/LEDRK5: U5.3, U36.43
/Input Keyscan and RGB LED Driver/LEDRK6: U6.3, U36.46
/Input Keyscan and RGB LED Driver/LEDRK7: U7.3, U36.49
/Input Keyscan and RGB LED Driver/LEDRK8: U8.3, U36.52
/Input Keyscan and RGB LED Driver/LEDRK9: U9.3, U36.5
/Input Keyscan and RGB LED Driver/LEDRK10: U10.3, U36.8
/Input Keyscan and RGB LED Driver/LEDRK11: U11.3, U36.11
/Input Keyscan and RGB LED Driver/LEDRK12: U12.3, U36.14
/Input Keyscan and RGB LED Driver/LEDRK13: U13.3, U36.17
/Input Keyscan and RGB LED Driver/LEDRK14: U14.3, U36.20
/Input Keyscan and RGB LED Driver/LEDRK15: U15.3, U36.23
/Input Keyscan and RGB LED Driver/LEDRK16: U16.3, U36.26
/Input Keyscan and RGB LED Driver/LEDRK17: U17.3, U37.52
/Input Keyscan and RGB LED Driver/LEDRK18: U18.3, U37.49
/Input Keyscan and RGB LED Driver/LEDRK19: U19.3, U37.46
/Input Keyscan and RGB LED Driver/LEDRK20: U20.3, U37.43
/Input Keyscan and RGB LED Driver/LEDRK21: U21.3, U37.40
/Input Keyscan and RGB LED Driver/LEDRK22: U22.3, U37.37
/Input Keyscan and RGB LED Driver/LEDRK23: U23.3, U37.34
/Input Keyscan and RGB LED Driver/LEDRK24: U24.3, U37.31
/Input Keyscan and RGB LED Driver/LEDRK25: U25.3, U37.26
/Input Keyscan and RGB LED Driver/LEDRK26: U26.3, U37.23
/Input Keyscan and RGB LED Driver/LEDRK27: U27.3, U37.20
/Input Keyscan and RGB LED Driver/LEDRK28: U28.3, U37.17
/Input Keyscan and RGB LED Driver/LEDRK29: U29.3, U37.14
/Input Keyscan and RGB LED Driver/LEDRK30: U30.3, U37.11
/Input Keyscan and RGB LED Driver/LEDRK31: U31.3, U37.8
/Input Keyscan and RGB LED Driver/LEDRK32: U32.3, U37.5
/MCU/MIDI_RX: R4.1, TP2.1, U33.16, U43.6
/MCU/MIDI_TX: TP50.1, U33.15, U42.2
/MCU/NRST: J7.10, U33.6
/MCU/SPI2_CLK: TP10.1, U33.32, U36.2, U37.2
/MCU/SPI2_GSCLK: TP11.1, U33.2, U36.55, U37.55
/MCU/SPI2_LAT: TP15.1, U33.1, U36.3, U37.3
/MCU/SPI2_MOSI: TP13.1, U33.31, U36.1
/MCU/SWDCLK: J7.4, R11.2, R12.1, U33.25
/MCU/SWDIO: J7.2, U33.24
/MCU/TIM1_CH1: R28.2, SW1.A, U33.18
/MCU/TIM1_CH2: R29.2, SW1.B, U33.19
/MCU/TIM1_SW: SW1.S1, U33.17
/OLED_Display/+3.3V_OLED: C25.1, D6.2, J8.2, TP9.1, U41.3
/OLED_Display/CLK: J8.3, TP55.1, U33.8
/OLED_Display/DATA: J8.4, TP54.1, U33.9
/OLED_Display/DATA_COMMAND: J8.6, TP52.1, U33.7
/OLED_Display/RESET: J8.5, TP53.1, U33.10
/PSU/+5V_RGB: C4.1, C5.1, C9.1, C10.1, D3.2, L1.2, R6.1, TP5.1, U1.4, U1.5, U1.6, U2.4, U2.5, U2.6, U3.4, U3.5, U3.6, U4.4, U4.5, U4.6, U5.4, U5.5, U5.6, U6.4, U6.5, U6.6, U7.4, U7.5, U7.6, U8.4, U8.5, U8.6, U9.4, U9.5, U9.6, U10.4, U10.5, U10.6, U11.4, U11.5, U11.6, U12.4, U12.5, U12.6, U13.4, U13.5, U13.6, U14.4, U14.5, U14.6, U15.4, U15.5, U15.6, U16.4, U16.5, U16.6, U17.4, U17.5, U17.6, U18.4, U18.5, U18.6, U19.4, U19.5, U19.6, U20.4, U20.5, U20.6, U21.4, U21.5, U21.6, U22.4, U22.5, U22.6, U23.4, U23.5, U23.6, U24.4, U24.5, U24.6, U25.4, U25.5, U25.6, U26.4, U26.5, U26.6, U27.4, U27.5, U27.6, U28.4, U28.5, U28.6, U29.4, U29.5, U29.6, U30.4, U30.5, U30.6, U31.4, U31.5, U31.6, U32.4, U32.5, U32.6, U36.54, U37.54
/PSU/PMOSReversePolarityProtection/VIN: Q1.3, SW3.1, TP3.1
/PSU/TPS563200_BUCK_MISC/BUCK_VIN: C1.1, C2.1, C15.1, C16.1, D1.1, D7.2, Q1.2, TP4.1, TP6.1, U38.3, U38.5, U39.3, U39.5
GND: C1.2, C2.2, C4.2, C5.2, C6.2, C7.2, C8.2, C9.2, C10.2, C11.2, C12.2, C13.2, C14.2, C15.2, C16.2, C18.2, C19.2, C20.2, C21.2, C22.2, C23.2, C24.2, C25.2, J5.2, J5.3, J7.3, J7.5, J7.9, J8.1, JP1.2, JP2.2, JP3.2, R5.1, R7.2, R8.2, R9.2, R12.2, R13.2, R26.2, R27.2, R32.2, SW1.C, SW1.S2, SW2.1, SW4.5, SW4.6, SW4.7, SW4.8, SW5.1, SW7.1, U33.5, U34.1, U34.32, U34.33, U35.19, U35.25, U36.29, U36.56, U36.57, U37.29, U37.56, U37.57, U38.1, U39.1, U40.1, U41.2, U42.3, U43.5
unnamed: C3.1, U38.6
unnamed: C3.2, L1.1, U38.2
unnamed: C17.1, U39.6
unnamed: C17.2, L2.1, U39.2
unnamed: D1.2, Q1.1, R5.2
unnamed: D2.1, R1.1, U43.2
unnamed: D2.2, J1.5, U43.3
unnamed: D3.1, R8.1
unnamed: D4.1, R9.1
unnamed: D5.1, R27.1
unnamed: D6.1, R32.1
unnamed: D7.1, R13.1
unnamed: J1.4, R1.2
unnamed: J2.4, R3.1
unnamed: J2.5, R2.2
unnamed: J5.1, SW3.2
unnamed: R2.1, U42.4
unnamed: R6.2, R7.1, U38.4
unnamed: R21.2, SW7.2, U34.31
unnamed: R25.2, R26.1, U39.4
unnamed: R30.1, SW2.3
unnamed: TP16.1, U36.28, U37.1

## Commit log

2021-06-05 Completed RevA schematics
    [10PinARMSWD.sch, 2_42Inch_OLED_LDO.sch, BassStation_Sequencer_MidiInterface.kicad_pcb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]
2021-06-07 RevA Layout draft completed
    - Needs tidy up
    - Add test points
    [010321021 2.stp, 10PinARMSWD.sch, 2-1879314-2.stp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]
2021-06-07 Added mounting holes to corners of layout
    [BassStation_Sequencer_MidiInterface.kicad_pcb]
2021-06-07 Completed RevA layout
    [BassStation_Sequencer_MidiInterface.kicad_pcb, LED_PCB_SW.sch, MCU.sch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]
2022-01-27 Added Keypad spacer STL models
    These plastic spacers will fit around the membrane keypad to keep downward pressure on the leypad when the front panel is in place.
    Photos showing the PCB assembly with and without.
    FYI no front panel has been design yet.
    [KeyPadSpacerV0.8 v11.stl, KeyPadSpacer_mirroredV0.8 v11.stl]
2022-02-08 updated for kicad 6
    [10PinARMSWD.kicad_sch, 2_42Inch_OLED_LDO.kicad_sch, BassStation_Sequencer_MidiInterface.kicad_sch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]
2022-02-08 updated SPI labels
    https://github.com/cracked-machine/BassStationSequencerMidiController/issues/3
    [BassStation_Sequencer_MidiInterface-B_Cu_SIGNAL.gbr, BassStation_Sequencer_MidiInterface-B_Mask.gbr, BassStation_Sequencer_MidiInterface-B_Paste.gbr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]
2022-02-09 updated user buttons
    removed dipsw, added four more tactile button (three above display, three below display, six total)
    [BassStation_Sequencer_MidiInterface-B_Cu_SIGNAL.gbr, BassStation_Sequencer_MidiInterface-B_Mask.gbr, BassStation_Sequencer_MidiInterface-B_Paste.gbr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]
2022-02-09 updated docs
    [10PinARMSWD.kicad_sch, 2_42Inch_OLED_LDO.kicad_sch, BassStation_Sequencer_MidiInterface.kicad_sch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]
2022-02-10 Add ground points
    https://github.com/cracked-machine/BassStationSequencerMidiController/issues/9
    Also, made space on layout for uSDCard IDC connector and DAC analog output section
    [BassStation_Sequencer_MidiInterface-B_Cu_SIGNAL.gbr, BassStation_Sequencer_MidiInterface-B_Mask.gbr, BassStation_Sequencer_MidiInterface-B_Paste.gbr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]
2022-02-11 updated layout DRC
    Fixed clearance errors with polygons and pads in switch footprints
    [BassStation_Sequencer_MidiInterface-B_Cu_SIGNAL.gbr, BassStation_Sequencer_MidiInterface-B_Mask.gbr, BassStation_Sequencer_MidiInterface-B_Paste.gbr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]
2022-04-15 Checked microSD card connector pins and added board layout connector footprint
    [BassStation_Sequencer_MidiInterface.kicad_sch, LED_PCB_SW.kicad_sch, MCU.kicad_sch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]
2022-04-15 updated save
    [BassStation_Sequencer_MidiInterface.kicad_sch, MicroSD.kicad_sch]
2022-06-24 Replaced Vias 0.4mm -> 0.45mm
    [BassStation_Sequencer_MidiInterface-B_Cu_SIGNAL.gbr, BassStation_Sequencer_MidiInterface-B_Mask.gbr, BassStation_Sequencer_MidiInterface-B_Paste.gbr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]

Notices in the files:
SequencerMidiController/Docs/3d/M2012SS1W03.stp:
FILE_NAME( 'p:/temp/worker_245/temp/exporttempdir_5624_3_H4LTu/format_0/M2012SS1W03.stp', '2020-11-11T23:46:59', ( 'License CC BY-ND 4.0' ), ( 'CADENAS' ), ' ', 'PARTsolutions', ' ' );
